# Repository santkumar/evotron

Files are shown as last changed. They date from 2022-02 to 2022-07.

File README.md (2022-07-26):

# evotron
Opentron OT-2 based automated sampling device for eVOLVER

## Preparation (summary)

* Hardware modifications: OT-2 sampling needle and tubings, eVOLVER modifications, Arduino 2560 Mega and pumps (sampling and waste-removal peristaltic pumps) integration 
* Save OT-2 protocol routines in the OT-2 raspberry pi system and run calibration to find location coordinates or vials and cleaning solution bottles (check ot2 folder).
* Modify eVOLVER dpu and conf.yml files (check evolver folder).
* Compile and upload the required code on Arduino 2560 Mega (check arduino folder).
* Prepare cytoflex experiment files and routines (check cytoflex folder).
* Modify MATLAB main file as per experiment (check matlab folder).

## To run

* First, run the eVOLVER experiment run routine (check eVOLVER manufacturer's instruction manual)
* In the MATLAB main.m file, modify **evolverExptDir** variable to the eVOLVER experiment folder location name. Modify other user input variables as required.
* Start MATLAB application as administrator. Run MATLAB main.m script.

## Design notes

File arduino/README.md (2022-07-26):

Arduino Mega 2560 controller acts as a bridge between the control computer, OT-2 and persitaltic pumps. Please use the **main** code in the **mega** folder for controller.

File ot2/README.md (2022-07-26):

**Note**

* Running these OT-2 protocol codes requires OT-2 server version 4.3.1 and protocol API version 2.0
* The protocol code assumes that sampling needle (CAD files for needle mount has been provided) is mounted on the left pipette head of OT-2. This can be easily modified if needed.

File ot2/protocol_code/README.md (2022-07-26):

Save these files (main_protocol.py and vial_xy_location.txt) in **/data/custom_protocols/** folder on the OT-2 raspberry pi system. Please look into calibration for the modifications needed in these two files.

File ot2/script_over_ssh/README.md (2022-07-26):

These files can be saved anywhere on the OT-2 raspberry pi system. Add this saved file location into the MATLAB main run script.

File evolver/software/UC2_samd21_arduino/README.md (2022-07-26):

Compile and upload RS485_LED.ino code onto UC2 SAMD21 arduino on the evolver platform.

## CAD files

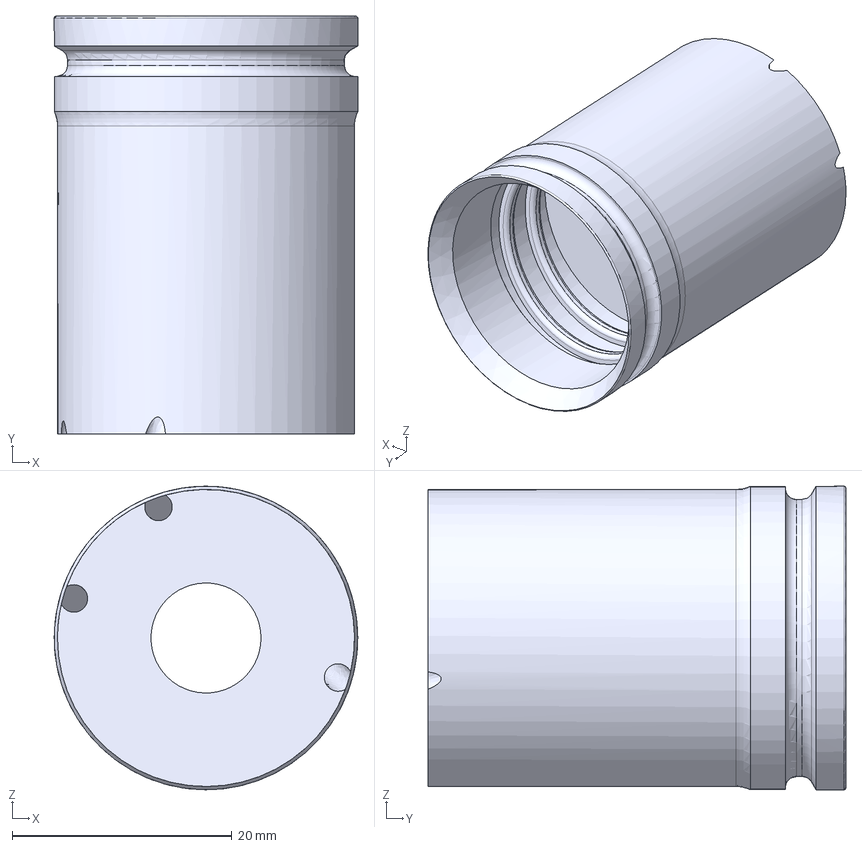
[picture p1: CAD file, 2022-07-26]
evolver/hardware/CAD/new_vial_cap.step
27.6 x 38.0 x 27.6 mm

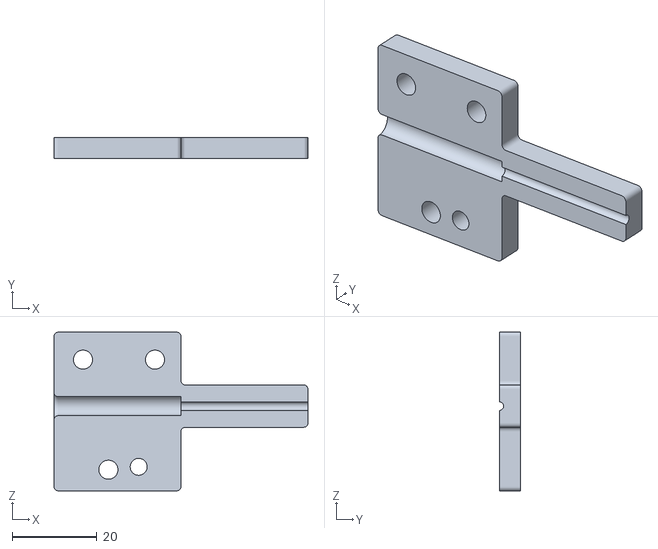
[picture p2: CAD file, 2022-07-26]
ot2/hardware/CAD/sampling_needle_mount_part_2.stl
60.0 x 5.00 x 37.5

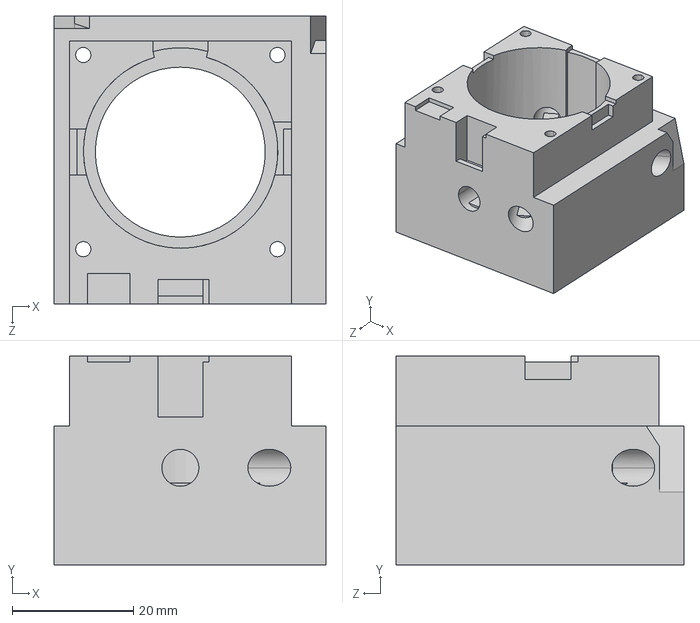
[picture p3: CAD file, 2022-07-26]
evolver/hardware/CAD/new_tube_holder.step
44.8 x 34.4 x 47.4 mm

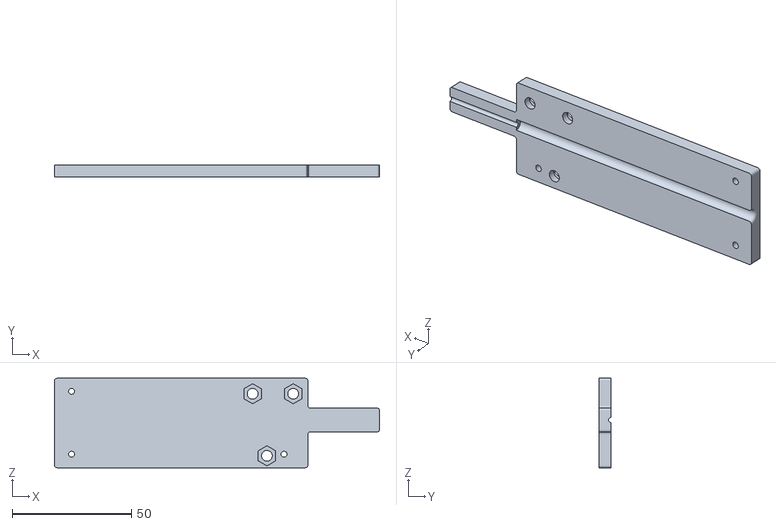
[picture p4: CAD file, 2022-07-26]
ot2/hardware/CAD/sampling_needle_mount_part_1.stl
136.1 x 5.00 x 37.5

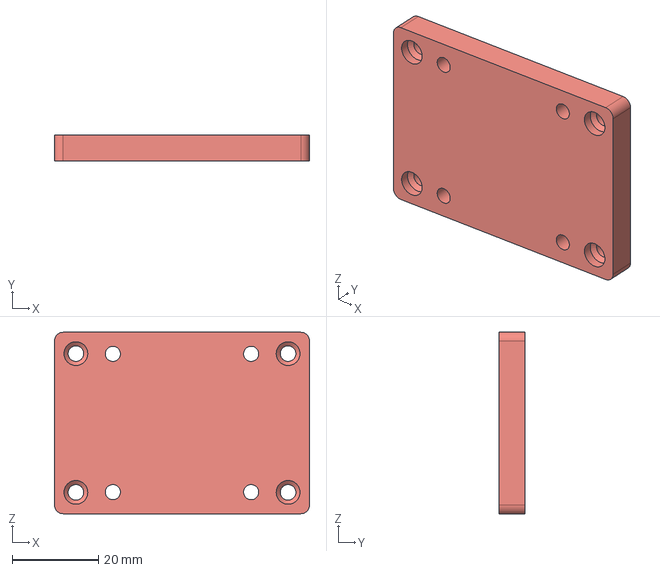
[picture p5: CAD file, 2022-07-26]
evolver/hardware/CAD/new_base_plate.step
59.0 x 6.00 x 42.0 mm

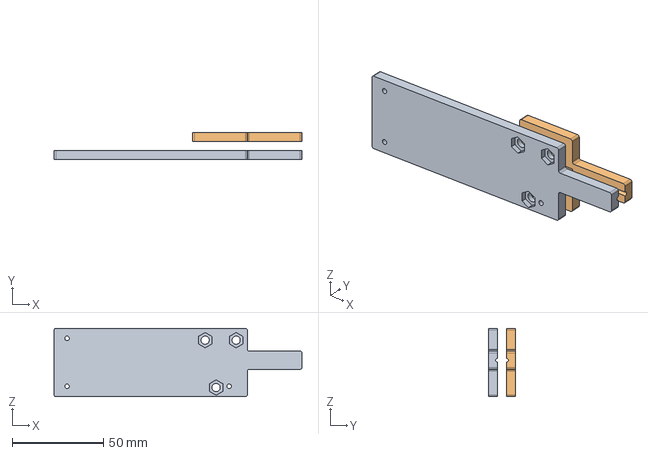
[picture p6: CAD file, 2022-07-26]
ot2/hardware/CAD/sampling_needle_mount.step
136.2 x 15.0 x 37.5 mm

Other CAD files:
evolver/hardware/CAD/new_base_plate.stl
evolver/hardware/CAD/new_tube_holder.stl
evolver/hardware/CAD/new_vial_cap.stl

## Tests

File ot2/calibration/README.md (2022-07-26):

**To get vials and sampling bottle locations on the OT-2 deck**

* Save *get_xyz_location.py* in */data/custom_protocols/* folder on the OT-2 raspberry pi system
* SSH into the OT-2 raspberry pi system
* Execute command: **cd /data/custom_protocols**
* Execute command: **opentrons_execute get_xyz_location.py**
* Enter the xyz coordinates as asked. Once the xy coordinate (such that the sampling needle can be lowered into the culture passing through the cap hole) of Vial #N has been found, note down the xy coordinates and then move to other vials. Same for the cleaning solution bottles.
* The xy coordinates of all the vials should be manually entered into **/data/custom_protocols/vial_xy_location.txt** file in ascending order in successive lines. The X and Y coordinates should be separated with a comma in the .txt file.
* The xy coordinates of cleaning solution bottles should be manually entered into **/data/custom_protocols/main_protocol.py** file as **xy_preWash**, **xy_bleach** and **xy_postWash** variables. The default **z_top**, **z_sample** and **z_wash** variables (in the same .py file) should also be modified if needed.
* Once all the desired locations have been found, press Ctrl + C.

**NOTE: Be careful while entering location coordinates. Any mistake might lead to sampling needle hitting the vials, cleaning bottles, or the OT-2 deck. A fail safe against these scenarios will be added in future releases.**

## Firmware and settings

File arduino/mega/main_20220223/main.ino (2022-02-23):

// Pinouts
const int samplingPumpEnablePin = 2;
const int samplingPumpSpeedPin = 3;   //PWM
const int wastePumpDirectionPin = 8;
const int wastePumpSpeedPin = 9;      //PWM
const int resetPin = 13;

// Durations (in milli-seconds)
const int t_samplingPumpStart = 500;
const int t_samplingPumpON = 40000;   //delaying this directly won't work as delay fn max out at 16383 (accurate delay)
const int t_wastePumpStart = 500;
const int t_wastePumpON = 10000;
const int t_waitBleach = 10000;

// Pump Speed (0 to 255)
const int samplingPumpSpeed = 255;
const int wastePumpSpeed = 255;

// String Input
String inputStringComputer = "";         // a string to store incoming data from Computer 
String inputStringOpentron = "";         // a string to store incoming data from Opentron 
boolean stringCompleteComputer = false;  // whether the string is complete (from Computer)
boolean stringCompleteOpentron = false;  // whether the string is complete (from Opentron)
boolean foundStartSequenceComputer = false;
boolean foundStartSequenceOpentron = false;
boolean receivedCmdSampling = false;

char startSequence = '!';
char endSequence = '?';

String vialNumString = "";
char vialNum1 = '1';    // initial random value
char vialNum2 = '3';    // initial random value
int vialNum = 5;        // initial random value

// Commands //

String cmdError = "!err?";
String cmdStopProgram = "!stp?";

// Computer comm
String cmdStartSampling = "!ssa?";
String cmdDoneSampling = "!dsa?";

String cmdRemoveSampleAndClean = "!rsc?";
String cmdDoneCleaning = "!dcl?";

// Opentron comm
String cmdMoveNeedleForSampling = "!mns?";
String cmdWhichVial = "!whv?";
String cmdDoneMoveNeedleForSampling = "!dmn?";

String cmdStartPreWash = "!spr?";
String cmdDonePreWash = "!dpr?";

String cmdStartBleach = "!sbl?";
String cmdDoneBleach = "!dbl?";

String cmdStartPostWash = "!spo?";
String cmdDonePostWash = "!dpo?";

void serialEventComputer() {
  while (Serial1.available()>0 && !stringCompleteComputer) {
    char inChar = (char)Serial1.read();
    if (inChar == startSequence){
      foundStartSequenceComputer = true;
    }
    if (foundStartSequenceComputer){
      inputStringComputer += inChar;
      if (inChar == endSequence) {
        stringCompleteComputer = true;
        foundStartSequenceComputer = false;
      }
    }        
  }
}

void serialEventOpentron() {
  while (Serial.available()>0 && !stringCompleteOpentron) {
    char inChar = (char)Serial.read();
    if (inChar == startSequence){
      foundStartSequenceOpentron = true;
    }
    if (foundStartSequenceOpentron){
      inputStringOpentron += inChar;
      if (inChar == endSequence) {
        stringCompleteOpentron = true;
        foundStartSequenceOpentron = false;
      }
    }        
  }
}

boolean compareCmds(String str1, String str2){
  int i;
  int len1 = sizeof(str1);
  int len2 = sizeof(str2);
  if (len1!=len2) return false;
  for (i=0; i<len1; i++) if (str1[i]!=str2[i]) return false;
  return true;
}

void startSamplingPump(){
  analogWrite(samplingPumpSpeedPin,samplingPumpSpeed);
  digitalWrite(samplingPumpEnablePin, LOW); // turn ON sampling pump
  delay(t_samplingPumpStart);  
}

void stopSamplingPump(){
  digitalWrite(samplingPumpEnablePin, HIGH);
  analogWrite(samplingPumpSpeedPin,0);
}

void startWastePump(){
  digitalWrite(wastePumpDirectionPin, HIGH);
  analogWrite(wastePumpSpeedPin, wastePumpSpeed); // turn ON waste pump
  delay(t_wastePumpStart);
}

void stopWastePump(){
  analogWrite(wastePumpSpeedPin, 0);  
}

void removeWaste(){
  startWastePump();
  delay(t_wastePumpON);
  stopWastePump();
}

void setup() {
  Serial1.begin(9600);  // comm with computer
  Serial.begin(9600);   // comm with opentron
  inputStringComputer.reserve(50);  
  inputStringOpentron.reserve(50);  
  //while(!Serial1);
  //while(!Serial);
  digitalWrite(samplingPumpEnablePin, HIGH);
  pinMode(samplingPumpEnablePin, OUTPUT);
  pinMode(samplingPumpSpeedPin, OUTPUT);

  digitalWrite(wastePumpDirectionPin, HIGH);
  pinMode(wastePumpDirectionPin, OUTPUT);
  pinMode(wastePumpSpeedPin, OUTPUT);

  digitalWrite(resetPin, HIGH);
  pinMode(resetPin, OUTPUT);
}

// 40 seconds wait
void waitForEmptyTube(){
  delay(10000);
  delay(10000);
  delay(10000);
  delay(10000);
}

void loop() {

  serialEventComputer();
  serialEventOpentron();

  if (stringCompleteComputer){
    stringCompleteComputer = false;
    if (compareCmds(inputStringComputer,cmdStartSampling)){
      Serial1.print(inputStringComputer); // send ack to computer
      inputStringComputer = "";
      startSamplingPump();
      receivedCmdSampling = true;
    }
    else if (receivedCmdSampling){
      Serial1.print(inputStringComputer); // send ack to computer
      vialNum1 = inputStringComputer[1];
      vialNum2 = inputStringComputer[2];
      vialNumString += vialNum1;
      vialNumString += vialNum2;
      inputStringComputer = "";
      vialNum = vialNumString.toInt();
      vialNumString = "";
      receivedCmdSampling = false;
      Serial.print(cmdMoveNeedleForSampling); // send move needle command to opentron
    }    
    else if (compareCmds(inputStringComputer,cmdRemoveSampleAndClean)){
      Serial1.print(inputStringComputer); // send ack to computer
      inputStringComputer = "";
      removeWaste(); // remove sample from cyto tube
      startSamplingPump();
      Serial.print(cmdStartPreWash); // send pre-wash command to opentron
    }
    else if (compareCmds(inputStringComputer,cmdStopProgram)){
      stopSamplingPump();
      Serial1.print(inputStringComputer); // send ack to computer
      inputStringComputer = "";
      digitalWrite(resetPin, LOW); // reset arduino
    }
                    
  }

  if (stringCompleteOpentron){
    stringCompleteOpentron = false;
    if (compareCmds(inputStringOpentron,cmdWhichVial)){
      inputStringOpentron = "";
      delay(1000); // wait for one second
      Serial.print(vialNum);
    }
    else if (compareCmds(inputStringOpentron,cmdDoneMoveNeedleForSampling)){
      inputStringOpentron = "";
      waitForEmptyTube();          // wait until the whole sample tube is emptied
      stopSamplingPump();          
      Serial1.print(cmdDoneSampling);   // send done sampling command to computer
    }
    else if (compareCmds(inputStringOpentron,cmdDonePreWash)){
      inputStringOpentron = "";
      waitForEmptyTube();          // wait until the whole sample tube is emptied
      stopSamplingPump();
      removeWaste();               // remove water from cyto tube
      startSamplingPump();                              
      Serial.print(cmdStartBleach); // send bleach command to opentron
    }
    else if (compareCmds(inputStringOpentron,cmdDoneBleach)){
      inputStringOpentron = "";
      waitForEmptyTube();          // wait until the whole sample tube is emptied
      stopSamplingPump();
      delay(t_waitBleach);         // let bleach solution in cyto tube for 10 seconds 
      removeWaste();               // remove bleach solution from cyto tube 
      startSamplingPump();                                  
      Serial.print(cmdStartPostWash); // send post-wash command to opentron
    }
    else if (compareCmds(inputStringOpentron,cmdDonePostWash)){
      inputStringOpentron = "";
      waitForEmptyTube();          // wait until the whole sample tube is emptied
      stopSamplingPump();
      removeWaste();
      Serial1.print(cmdDoneCleaning);   // send done waste removal and clean command to computer          
    }        
  }

}

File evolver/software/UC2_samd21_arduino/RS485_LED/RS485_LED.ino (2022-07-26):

// Recurring Command: 'od_ledr,4095,4095,4095,4095,4095,4095,4095,4095,4095,4095,4095,4095,4095,4095,4095,4095,_!"
// Immediate Command: 'od_ledi,4095,4095,4095,4095,4095,4095,4095,4095,4095,4095,4095,4095,4095,4095,4095,4095,_!"
// Acknowledgement to Run: "od_leda,0,0,0,0,0,0,0,0,0,0,0,0,0,0,0,0,_!"

// Recurring Command: 'opto_ledr,4095,4095,4095,4095,4095,4095,4095,4095,4095,4095,4095,4095,4095,4095,4095,4095,_!"
// Immediate Command: 'opto_ledi,4095,4095,4095,4095,4095,4095,4095,4095,4095,4095,4095,4095,4095,4095,4095,4095,_!"
// Acknowledgement to Run: "opto_leda,0,0,0,0,0,0,0,0,0,0,0,0,0,0,0,0,_!"

#include <evolver_si.h>
#include <Tlc5940.h>

// String Input
String inputString = "";         // a string to hold incoming data
boolean stringComplete = false;  // whether the string is complete
boolean serialAvailable = true;  // if serial port is ok to write on

//General Serial Communication
String comma = ",";
String end_mark = "end";
int num_vials = 16;
int active_vial = 0;

// OD LED Settings
String od_led_address = "od_led";
evolver_si od_led("od_led", "_!", num_vials+1); // 17 CSV-inputs from RPI
boolean new_odLEDinput = false;
int saved_odLEDinputs[] = {4095,4095,4095,4095,4095,4095,4095,4095,4095,4095,4095,4095,4095,4095,4095,4095};

// OPTO LED Settings
String opto_led_address = "opto_led1";
evolver_si opto_led("opto_led1", "_!", num_vials+1); // 17 CSV-inputs from RPI
boolean new_optoLEDinput = false;
int saved_optoLEDinputs[] = {4095,4095,4095,4095,4095,4095,4095,4095,4095,4095,4095,4095,4095,4095,4095,4095};

void setup() {
  pinMode(12, OUTPUT);
  digitalWrite(12, LOW);
  Tlc.init(RIGHT_PWM | LEFT_PWM,4095); // for both OD and OPTO LED (Left is OD and Right is OPTO)
  Serial1.begin(9600);
  SerialUSB.begin(9600);
  // reserve 1000 bytes for the inputString:
  inputString.reserve(1000);
  while (!Serial1);

  for (int i = 0; i < num_vials; i++) {
    Tlc.set(LEFT_PWM, i, 4095 - saved_odLEDinputs[i]);
  }
  while(Tlc.update());

  for (int i = 0; i < num_vials; i++) {
    Tlc.set(RIGHT_PWM, i, 4095 - saved_optoLEDinputs[i]);
  }
  while(Tlc.update());

}

void loop() {
  serialEvent();
  if (stringComplete) {
    SerialUSB.println(inputString);
    od_led.analyzeAndCheck(inputString);
    opto_led.analyzeAndCheck(inputString);

    // Clear input string, avoid accumulation of previous messages
    inputString = "";
        
    // OD LED Logic
    if (od_led.addressFound) {
      if (od_led.input_array[0] == "i" || od_led.input_array[0] == "r") {
        SerialUSB.println("Saving OD LED Setpoints");
        for (int n = 1; n < num_vials+1; n++) {
          saved_odLEDinputs[n-1] = od_led.input_array[n].toInt();
        }
        
        SerialUSB.println("Echoing New OD LED Command");
        new_odLEDinput = true;
        echoODLED();
        
        SerialUSB.println("Waiting for OK to execute...");
      }
      if (od_led.input_array[0] == "a" && new_odLEDinput) {
        update_odLEDvalues();
        SerialUSB.println("Command Executed!");
        new_odLEDinput = false;               
      }
      
      od_led.addressFound = false;
      inputString = "";
    }

    // OPTO LED Logic
    if (opto_led.addressFound) {
      if (opto_led.input_array[0] == "i" || opto_led.input_array[0] == "r") {
        SerialUSB.println("Saving OPTO LED Setpoints");
        for (int n = 1; n < num_vials+1; n++) {
          saved_optoLEDinputs[n-1] = opto_led.input_array[n].toInt();
        }
        
        SerialUSB.println("Echoing New OPTO LED Command");
        new_optoLEDinput = true;
        echoOPTOLED();
        
        SerialUSB.println("Waiting for OK to execute...");
      }
      if (opto_led.input_array[0] == "a" && new_optoLEDinput) {
        update_optoLEDvalues();
        SerialUSB.println("Command Executed!");
        new_optoLEDinput = false;               
      }
      
      opto_led.addressFound = false;
      inputString = "";
    }

    // Clears strings if too long
    // Should be checked server-side to avoid malfunctioning
    if (inputString.length() > 2000){
      SerialUSB.println("Cleared Input String");
      inputString = "";
    }
  }

  // clear the string:
  stringComplete = false;
}

void serialEvent() {
  while (Serial1.available()) {
    char inChar = (char)Serial1.read();
    inputString += inChar;
    if (inChar == '!') {
      stringComplete = true;
      break;
    }
  }
}

void echoODLED() {
  digitalWrite(12, HIGH);
  
  String outputString = od_led_address + "e,";
  for (int n = 1; n < num_vials+1 ; n++) {
    outputString += od_led.input_array[n];
    outputString += comma;
  }
  outputString += end_mark;
  delay(100);
  if (serialAvailable) {
    SerialUSB.println(outputString);
    Serial1.print(outputString);
  }  
  delay(100);
  digitalWrite(12, LOW);
}

void echoOPTOLED() {
  digitalWrite(12, HIGH);
  
  String outputString = opto_led_address + "e,";
  for (int n = 1; n < num_vials+1 ; n++) {
    outputString += opto_led.input_array[n];
    outputString += comma;
  }
  outputString += end_mark;
  delay(100);
  if (serialAvailable) {
    SerialUSB.println(outputString);
    Serial1.print(outputString);
  }  
  delay(100);
  digitalWrite(12, LOW);
}

void update_odLEDvalues() {
  for (int i = 0; i < num_vials; i++) {
    Tlc.set(LEFT_PWM, i, 4095 - saved_odLEDinputs[i]);
  }
  while(Tlc.update());
}

void update_optoLEDvalues() {
  for (int i = 0; i < num_vials; i++) {
    Tlc.set(RIGHT_PWM, i, 4095 - saved_optoLEDinputs[i]);
  }
  while(Tlc.update());
}

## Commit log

2021-06-07 added code for arduino mega
2021-06-07 added sampling pump control
2021-06-14 ported the whole code to arduino mega
2021-06-18 added evolver vial cap designs
    [vial_cap_full.stl, vial_cap_half.stl]
2021-06-21 added test code for sampling and waste pumps
2021-06-21 added waste pump functionality
2021-06-27 modified vial cap design (test)
    [vial_cap_full_v2.stl]
2021-06-28 solved arduino-matlab serial reliability issue (added check on command start sequence)
    [main.ino]
2021-06-28 added final vial-cap CAD version
    [vial_cap_full_v3.stl]
2021-06-30 added program stop/reset in arduino
    [main.ino]
2022-07-26 added evolver and ot2 running codes + CAD files
    [new_base_plate.step, new_base_plate.stl, new_tube_holder.step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]
2022-07-26 updated with current running cytoflex and matlab codes
